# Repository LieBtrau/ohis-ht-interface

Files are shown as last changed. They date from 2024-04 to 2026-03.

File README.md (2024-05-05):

# OHIS-interface
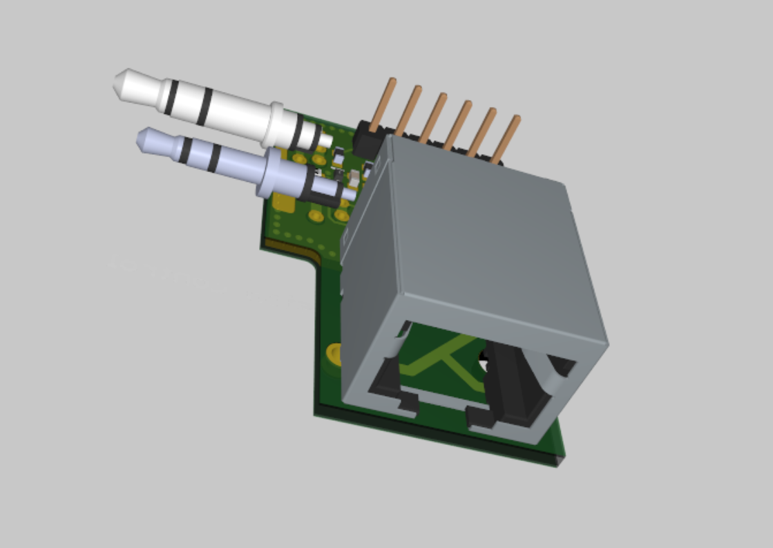
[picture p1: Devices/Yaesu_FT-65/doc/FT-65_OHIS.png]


According to [the OHIS-reference document](https://open-headset-interconnect-standard.github.io/ohis/Open-Headset-Interconnect-Standard.pdf):
> With the Open Headset Interconnect Standard, or OHIS, the club/EOC can build/buy one adapter for every
radio which stays with that radio, and the user only needs to build/buy one adapter for their specific headset
which stays with their headset, and now they can achieve full interoperability with only O(N) adapters.

# Criticism to OHIS
* Too many rigs are already using 8C/8p-modular jack connectors, but with a different pinout.  There's a big chance of breaking the radio if you plug in the wrong headset.
* The hook on the modular jack easily breaks if you don't protect it.
* One ground wire for mic and a separate ground wire for everything else would be enough instead of all the ground wires in the OHIS standard.
* When compared to a 3.5mm TRRS jack and cable, the modular jack is quite a bulky connector.

# Alternative interfaces
## CAIRO
* [CAIRO](https://web.archive.org/web/20060618023257/http://www-users.aston.ac.uk/~bestpj/cairo/manual/engineering.html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) : based on DIN-connectors, which are quite big as well.  They are however relatively common, cheap and easy to find.

## SATA-interface
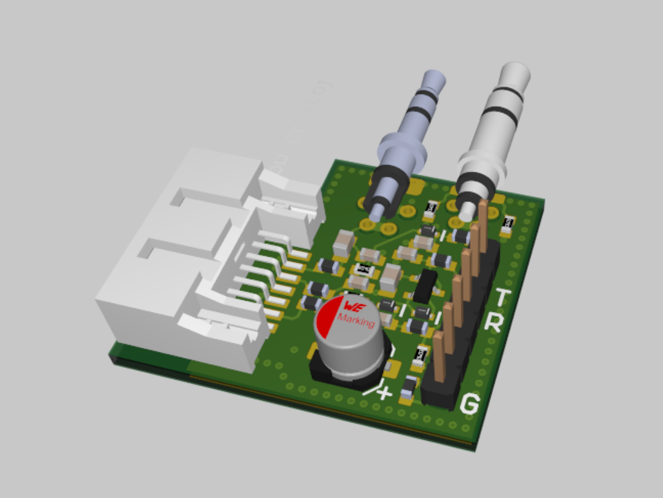
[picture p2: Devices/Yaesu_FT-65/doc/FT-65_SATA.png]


The SATA-interface is a low profile alternative to the modular jack.  It's easy to find cheap cables and connectors for it.  The SATA-connector has a locking mechanism, which is a big advantage over the TRS-jack.

Just to make it clear : this is not a SATA-interface, so you can't connect it to your hard drive.  We use the SATA-connector, but don't follow the SATA standard.  Confusion is very unlikely because the use case here is very different from the normal use case inside a computer.

The SATA connector has two differential pairs and three ground wires.  The differential pairs are used for the speaker, microphone, PTT and power.  The ground wires are used as current return path.  

| Pin | Signal | Description |
| --- | --- | --- |
| 1 | GND | Ground |
| 2 | SPK | Speaker |
| 3 | VCC | Power, max 5V, 200mA |
| 4 | GND | Ground |
| 5 | PTT | Push-To-Talk |
| 6 | MIC | Microphone |
| 7 | GND | Ground |

# Interface boards
This repostiory contains interface boards for the OHIS and SATA interfaces.  The interface boards are designed in Altium.

## Yaesu FT-65E
The OHIS- and SATA-interface to the FT-65E are also providing a pin header for UART interface to the radio.  This allows you to program the radio using a USB-UART converter and [CHIRP](https://chirpmyradio.com/projects/chirp/wiki/Home).  

* [Radio technical doc](./Devices/Yaesu_FT-65/Yaesu_FT65-E.ipynb)
* [OHIS FT-65E interface, version 1.0.0 (Altium online viewer)](https://365.altium.com/files/52D7B6AC-E25B-4030-AC4F-B64CA4D52889)
* [SATA FT-65E interface, version 1.0.0 (Altium online viewer)](https://365.altium.com/files/A41D46D5-1541-4C2A-84D1-905C59505208)

## Midland G9 Pro
* [Radio technical doc](./Devices/Midland_G9_Pro/MidlandG9pro.md)

These interfaces might work on more radios, but they have only been tested on the radios listed above.

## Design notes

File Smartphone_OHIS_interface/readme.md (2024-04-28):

# Measurements
## Maximum mic level
### Hardware setup
1. Connect TRS-cable to sound card (Tip=audio out, Sleeve=GND). 
2. Connect a TRRS-cable to the smartphone (Sleeve=MIC, R2=GND).
3. Connect audio out of TRS with a capacitor to MIC of TRRS.
4. Connect an oscilloscope parallel to the TRRS-cable connections.
5. Connect a 1K resistor from MIC to GND.  The internal microphone of a smartphone headset has the same value.

### Software setup
1. Smartphone runs [Phyphox](https://phyphox.org/) : Audio Scope
2. Laptop runs [REW](https://www.roomeqwizard.com/) : Generator
3. Generator set to 0dB.
4. Increase output volume setting of the laptop just before clipping occurs on the Audio Scope.

### Result
Maximum mic level is 30mVrms before clipping occurs.

## Maximum headphone level
### Hardware setup
1. Connect TRRS-cable to the smart phone
2. Connect oscilloscope between TIP and R2.

### Software setup
1. Smartphone runs [Phyphox](https://phyphox.org/) : Tone Generator
2. Set frequency to 1kHz
3. Set audio level of smartphone to maximum

### Result
AC-level = 457mVrms, DC-offset = 0V

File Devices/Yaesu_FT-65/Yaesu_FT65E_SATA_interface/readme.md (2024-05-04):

# Headphones
* 0dBV to -10dBV into a 16ohm to 64ohm load, a series resistor will be needed to drop the voltage to the correct level.
* No audio transformers because the radio only has 1 ground connection
* The radio has an H-bridge output stage.  The output is at 1.85V when no audio is present.  A capacitor is used to block the DC voltage.
* A small capacitor, parallel to the headphones, is used to filter out the high frequency noise.
* Only one channel is used to feed both headphones.  The radio has a mono output.  This reduces the number of components needed.

# Microphone
* The SATA interface is AC-coupled to the radio, but that should not be needed.  The 1uF can be replaced by a 0ohm resistor.

# Connection to the radio
* TRS-plugs (3.5mm and 2.5mm) and can be soldered directly to the interface:
  * Solder sleeve to the PCB.
  * Solder tip and ring using a loops of wire through two holes on either side of the plug.
* No filtering on TRS-plugs.
* GND of radio is directly connected to GND of interface.

# Connection to a sound card
Might also be connected to [Ai-thinker esp32-audio-kit](https://docs.ai-thinker.com/en/esp32-audio-kit), which uses an [ESP32-A1S module](https://docs.ai-thinker.com/_media/esp32-a1s_v2.3_specification.pdf)
Requires two 3.5mm TRS-jacks.  One for (line) input and one for (headphone) output.

# Isolation
If isolation is really needed, then an OHIS-OHIS interface could be created that contains two audio transformers.

# Connection to UART interface
* 6 pin JST XH connector (2.5mm pitch) to avoid wrong connection
* USB-UART bridge:
  * [Adafruit CP2102N Friend - USB to Serial Converter](https://www.adafruit.com/product/5335)
  * [Adafruit 70](https://www.adafruit.com/product/70)
  * [FTDI  TTL-232R-3V3](https://ftdichip.com/products/ttl-232r-3v3/)

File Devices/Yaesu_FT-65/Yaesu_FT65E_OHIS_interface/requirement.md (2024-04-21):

# Requirement
1. OHIS-compliant interface to handheld radio
2. Small form factor
3. Has 6 pin serial interface for programming
4. Solder pads for a custom cable
5. Plugs directly in the radio, avoiding custom cables or adapters
6. RF-filtering on all IO-connections
7. Clear labeling of all connectors

# Optional
1. audio jacks for connecting to a sound card or other audio device

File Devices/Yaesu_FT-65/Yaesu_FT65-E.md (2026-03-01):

## Yaesu FT-65E
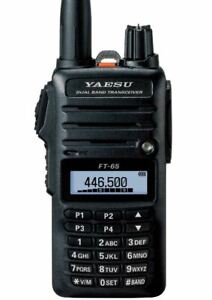
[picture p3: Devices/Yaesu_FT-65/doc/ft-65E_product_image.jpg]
Yaesu FT-65E product image
 

### Radio settings
#### Transmit power
* 0.5 W (Low)
* 2.5 W (Middle)
* 5.0 W (High)

#### Receiver sensitivity
* 0.2 μV (-121dBm) for 12 dB [SINAD](https://en.wikipedia.org/wiki/SINAD) (420 - 470 MHz, NFM)

#### PMR446
European version of the FT-65 can listen to PMR446, but is not allowed to transmit on that band.  Transmission on PMR446 is only allowed with PMR446-certified radios (fixed antenna, TX-power limited to 0.5W, ...), which the FT-65E is clearly not.

It's however technically possible to use a Yaesu FT-65E on PMR446:

1. Expand TX-range of a Yaesu FT-65E outside the ham-bands using this guide [here](https://simonthewizard.com/2017/12/17/yaesu-ft-65-expand/).
2. Set the following menu options in the FT-65E:
    * **32 : TX Power** : LOW (which is 0.5W)
    * **37 : WIDE/NAR** : NARROW (+/-2.5kHz deviation), when set to wide the Midland cuts off reception above 800Hz.
3. Set the TX-frequency equal to that of a PMR446-radio.
4. Frequency step : 
    * **30 : STEP** : 6.25kHz
5. Squelch type:
    * CTCSS:
      * **8 : CTCSS** : set up the same as a PMR446-radio.  On Kenwood PMR446 handsets, this will be called "Quiet Talk (QT)" setting, but it's essentially the same thing.
      * **29 : SQL Type** : TSQL
    * DCS:
      * **11 : DCS-code** : e.g. RX : 754, TX : 754
      * **29 : SQL Type** : DCS
6. Monitor / Tone calling.  The monitor button can be repurposed to send tone calling signals:
    * **9 : MONI/T.CALL** : 
      * MONITOR : monitor button is used to open squelch
      * other settings are for tone burst
     
### Antenna
During the tests:
* Set the TX power level (32:TX PWR) to LOW (0.5W)
* Replace the antenna by an RP-SMA to SMA adapter and add a 50Ω terminator.

### Audio IO
Don't turn the volume knob more than 50% to avoid distortion.  
Maximum undistorted audio output is 4.65Vpp, 1.85Voffset at 1kHz.

Maximum analog input voltage peak-peak for the Yaesu FT-65E = **30mVpp**

#### TX-Delay
This is the delay needed between pushing the PTT-button and the FT-65E being ready to transmit.  The delay is measured using a 1kHz sine wave signal.

* From Yaesu PTT-down to Midland G9 Pro opening its squelch = <144ms.
* From Yaesu PTT-down to Midland G9 Pro which has squelch-open all the time = <110ms.  Most of the times, it's between 80ms and 100ms.

#### TX-Tail
This is the delay needed between releasing the PTT-button and the FT-65E stopping to transmit.  The delay is measured using a 1kHz sine wave signal.

* From Yaesu PTT-up to Midland G9 Pro (squeltch-open all the time) = <170ms.  Most of the times, it's between 120ms and 140ms.

Motorola M1 connector : 7.62mm spacing between TRS-jacks.
* The threaded insert has an unknown screw thread.  It's close to M2.5, but not exactly the same.
* 3.5mm : 
  * Tip = speaker- (Vcm = 2.5V)
    * Jumps to 2V when squelch is open.  Audio max = 4V (with respect to GND)
  * Ring = ?
    * internal 10K PU to 3V3, unknown purpose
    * Short circuited to sleeve when using the SSM-17B Hand speaker Mic. Maybe that's the reason why Yaesu doesn't market the SSM-17B as an accessory to the FT-65.  The SSM-512B is advised instead.
  * Sleeve = speaker+ (Vcm = 2.5V)
* 2.5mm : 
  * Tip = Connect a PTT switch in series with electret-MIC (1K8 or 2K2 internal resistance) connected to GND.  Function generator outputs must be AC-coupled to this input, otherwise the PTT functionality no longer works correctly.
  * Ring = RX/TX line
    * RX/TX Short circuited to sleeve when using the SSM-17B Hand speaker Mic.
    * Use open drain TX and connect it to RX.  
    * To interface to a standard UART: connect the anode of a diode to the UART-RX. Connect the cathode of that same diode to the UART-TX. 
  * Sleeve = GND
    
### References
* [Packet radio projects (including APRS)](https://sites.google.com/site/rio4br/Home/aprs)
* [Ham.stackexchange.com](https://ham.stackexchange.com/questions/11776/what-is-the-external-mic-speaker-pinout-for-the-yaesu-ft-4xr-ft-65r-ft-25r)
* [Autocom intercom integration](http://largiader.com/electric/autocom.html)
* [BOMMEOW PARENT-BCT35-M1 3-Wire Acoustic Clear Tube Earpiece for Motorola Mototrbo CLS1410 XT460 DLR1020 Bearcom](https://www.bommeow.com/products/bommeow-parent-bct35-m1-3-wire-acoustic-clear-tube-earpiece-for-motorola-mototrbo-cls1410-xt460-dlr1020-bearcom)

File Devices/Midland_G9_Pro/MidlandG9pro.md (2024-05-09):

# Midland G9 Pro

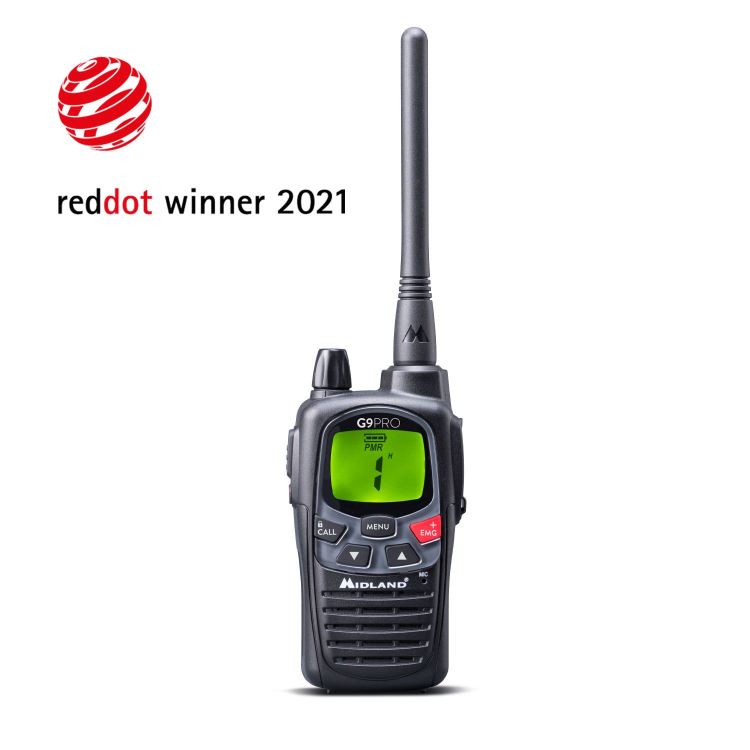
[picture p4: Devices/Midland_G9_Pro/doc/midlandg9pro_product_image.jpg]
Midland G9 Pro product image
 

* [User manual](0e696682f9c9f13678aeb36db453cce81be4fc38_MANUAL_G9_PRO_UK.pdf)
* Costs around €80 - €100.

## Disadvantages
* LCD-screen viewing angle is limited.
 
## Radio settings
### TX-output power
* L = 10mW
* H = 500mW

### Receiver sensitivity
* 0.35µV (-116dBm) (12dB [SINAD](https://en.wikipedia.org/wiki/SINAD))

### Channel settings
* [Channel list](./doc/8f8ebdc9da1fd9110cbd3557c7c3e5df0c08e5ac_CHANNELS_G9_PRO.pdf)

The radio can work with two different PMR-channel sets:
1. G9 PRO traditional band : 8 frequencies (from 446.00625MHz to 446.09375 MHz, 12.5kHz steps)
   * channels 1 to 8 : with configurable CTCSS/DCS
   * channels 9 to 16 : with CTCSS fixed to code 16 (114.8 Hz)
   * channels 17 to 24 : with CTCSS fixed to code 31 (192.8 Hz)
2. G9 PRO (new band) : 16 frequencies (from 446.00625MHz to 446.19375 MHz, 12.5kHz steps)
   * channels 1 to 16 : with configurable CTCSS/DCS
   * channels 17 to 32 : with CTCSS set to code 16 (114.8 Hz)

### Squelch
Opening the squelch/monitor : keep pressed for about 2 seconds both ▲▼ at the same time. Follow the same procedure to deactivate the function, or
switch off and on the radio.

#### DCS codes
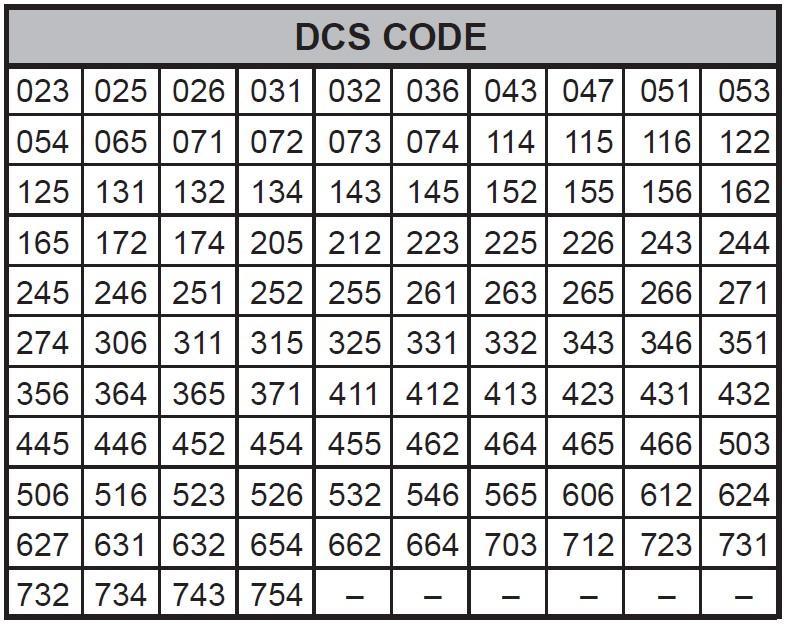
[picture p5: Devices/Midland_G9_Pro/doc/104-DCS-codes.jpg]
DCS-codes


#### CTCSS codes
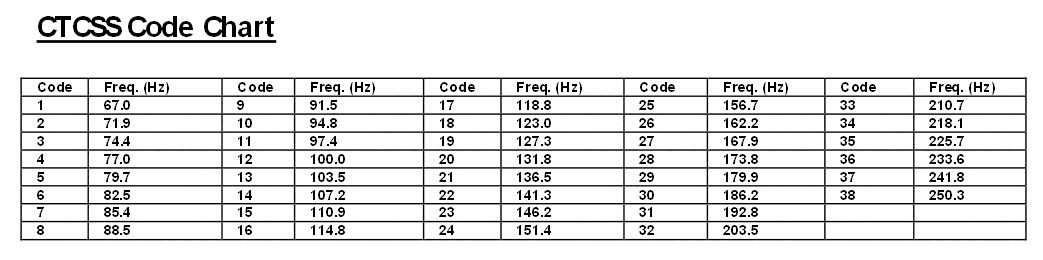
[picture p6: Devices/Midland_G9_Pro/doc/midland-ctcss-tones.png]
CTCSS-tones


## Audio IO
Midland 2prong pinout

* 3.5mm : 
  * Tip = Speaker + : 
  * Ring = ?
  * Sleeve = GND (Speaker -)
* 2.5mm : 
  * Tip = MIC_IN
    * Option 1 : Connect a PTT switch in series with electret-MIC (1K internal resistance)
    * Option 2 : Connect audio output of TNC between MIC_IN and GND.  Add a 2K2 resistor between MIC_IN and GND to activate PTT.
  * Ring = ?
  * Sleeve = GND (connected to 3.5mm sleeve inside the radio)

Don't fit a Kenwood K-1 connector in here.  It fits, but the pinout is different.
  
### Analog output
* Maximum audio output level is about 3Vpp.  Be careful : turning your volume knob open too far will cause your audio to clip, causing heavy distorted sound.
* Vcm when no audio is present = 2.40V
* Vcm when producing audio at max amplitude = 2.50V

### Analog input
PTT is activated by pulling MIC-IN to GND with a 2.2K resistor.

#### TX-Delay
Tested with 1kHz sine wave.
* From PTT down to squelch opening on FT-65 : <200ms, most of the times around 150ms.
* From PTT down to FT-65 receiving audio (with squelch continuously open) : <150ms, most of the times around 100ms.

#### TX-tail
Tested with 1kHz sine wave.
* From PTT up to squelch closing on FT-65 : <400ms
* From PTT up to FT-65 (with squelch continuously open) not receiving audio anymore : <350ms

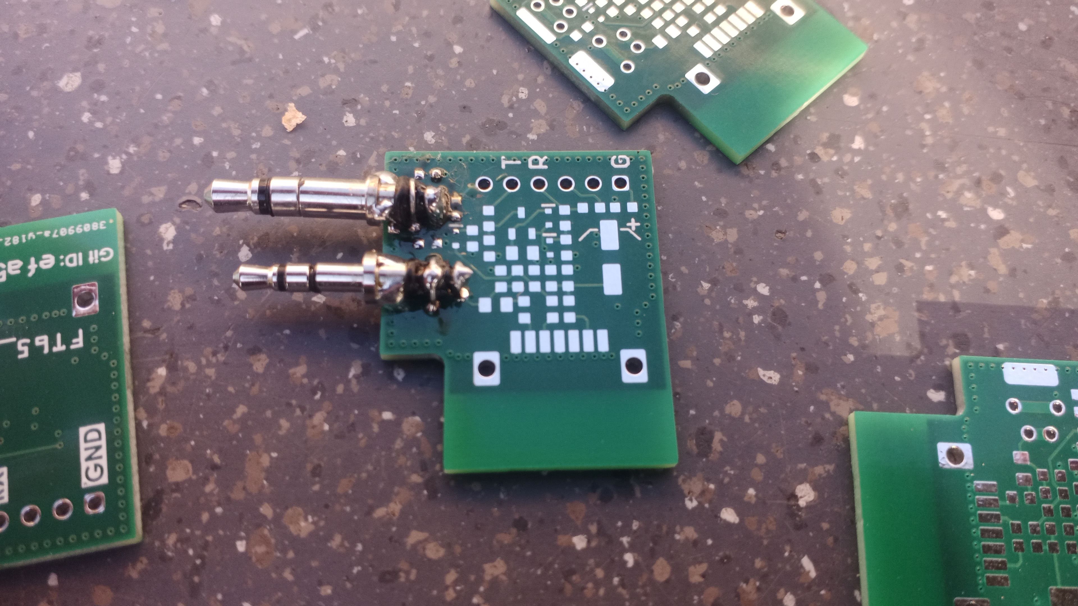
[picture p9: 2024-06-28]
pix/molten_connector.jpg

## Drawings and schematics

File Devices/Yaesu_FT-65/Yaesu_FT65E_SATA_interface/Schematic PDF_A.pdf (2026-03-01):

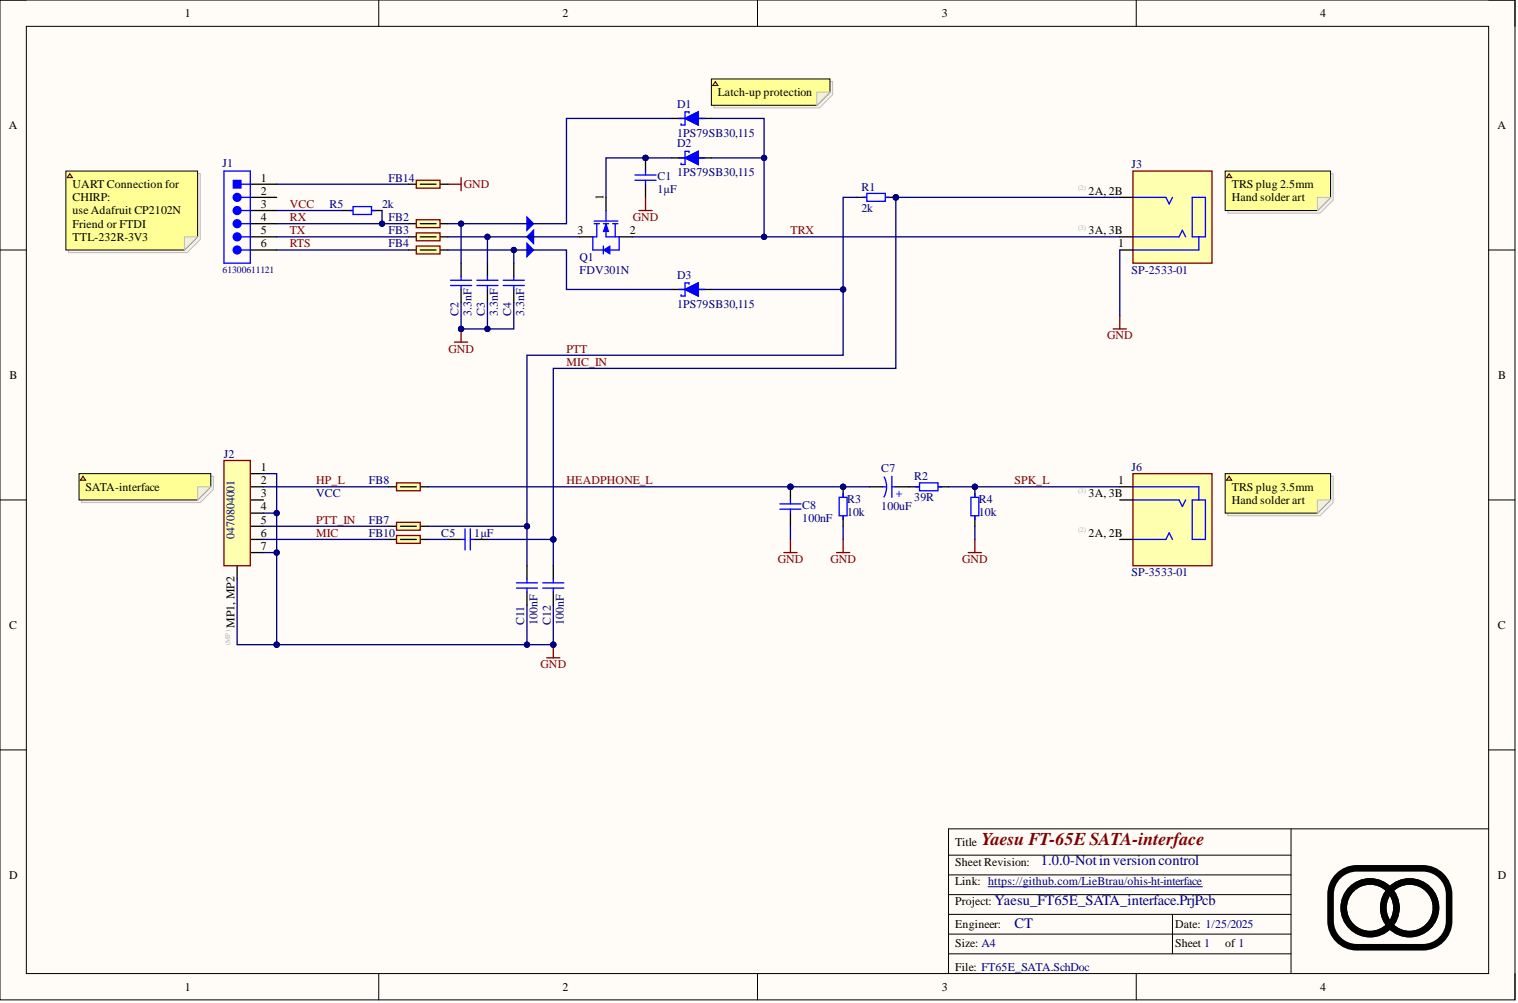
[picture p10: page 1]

GND | C1

Q1 FDV301N

PTT

3 | VCC

Yaesu FT-65E SATA-interface
Title
Sheet Revision:
Link: https://github.com/LieBtrau/ohis-ht-interface
Project:

1.0.0-Not in version control

Engineer: CT | Date: 1/25/2025
Size: A4 | Sheet 1 of 1

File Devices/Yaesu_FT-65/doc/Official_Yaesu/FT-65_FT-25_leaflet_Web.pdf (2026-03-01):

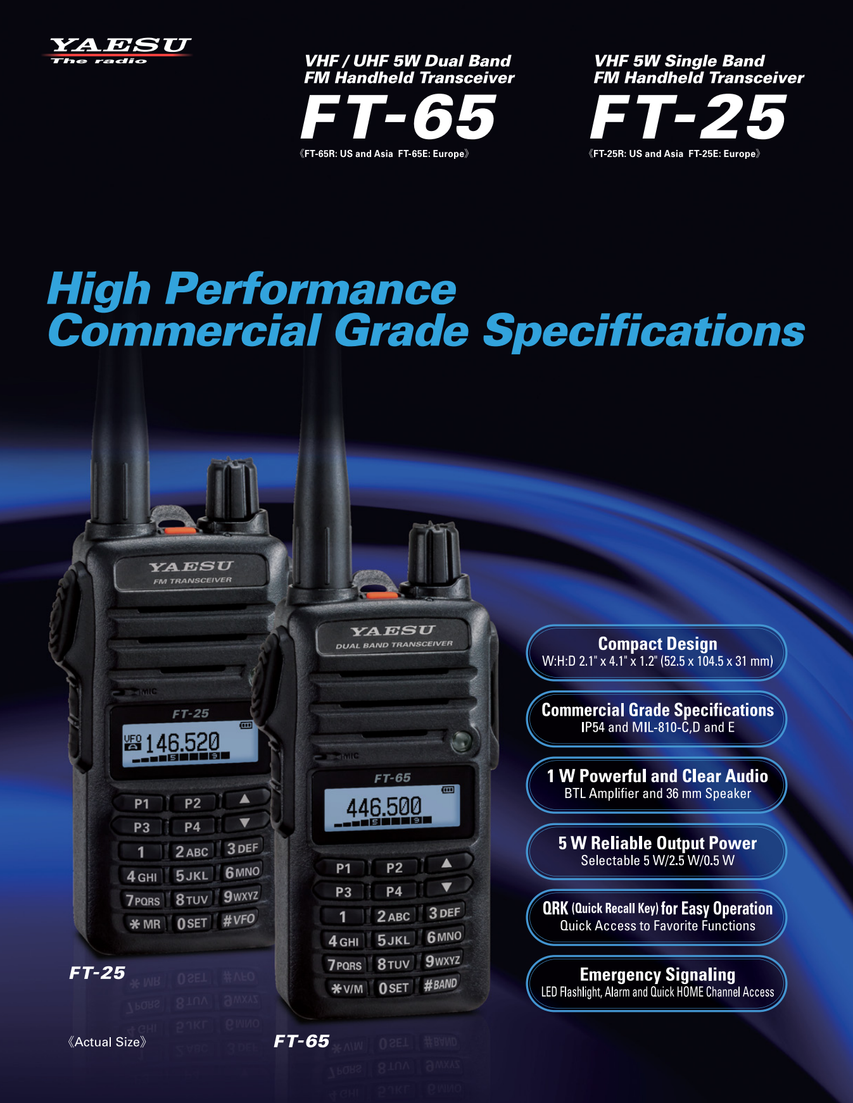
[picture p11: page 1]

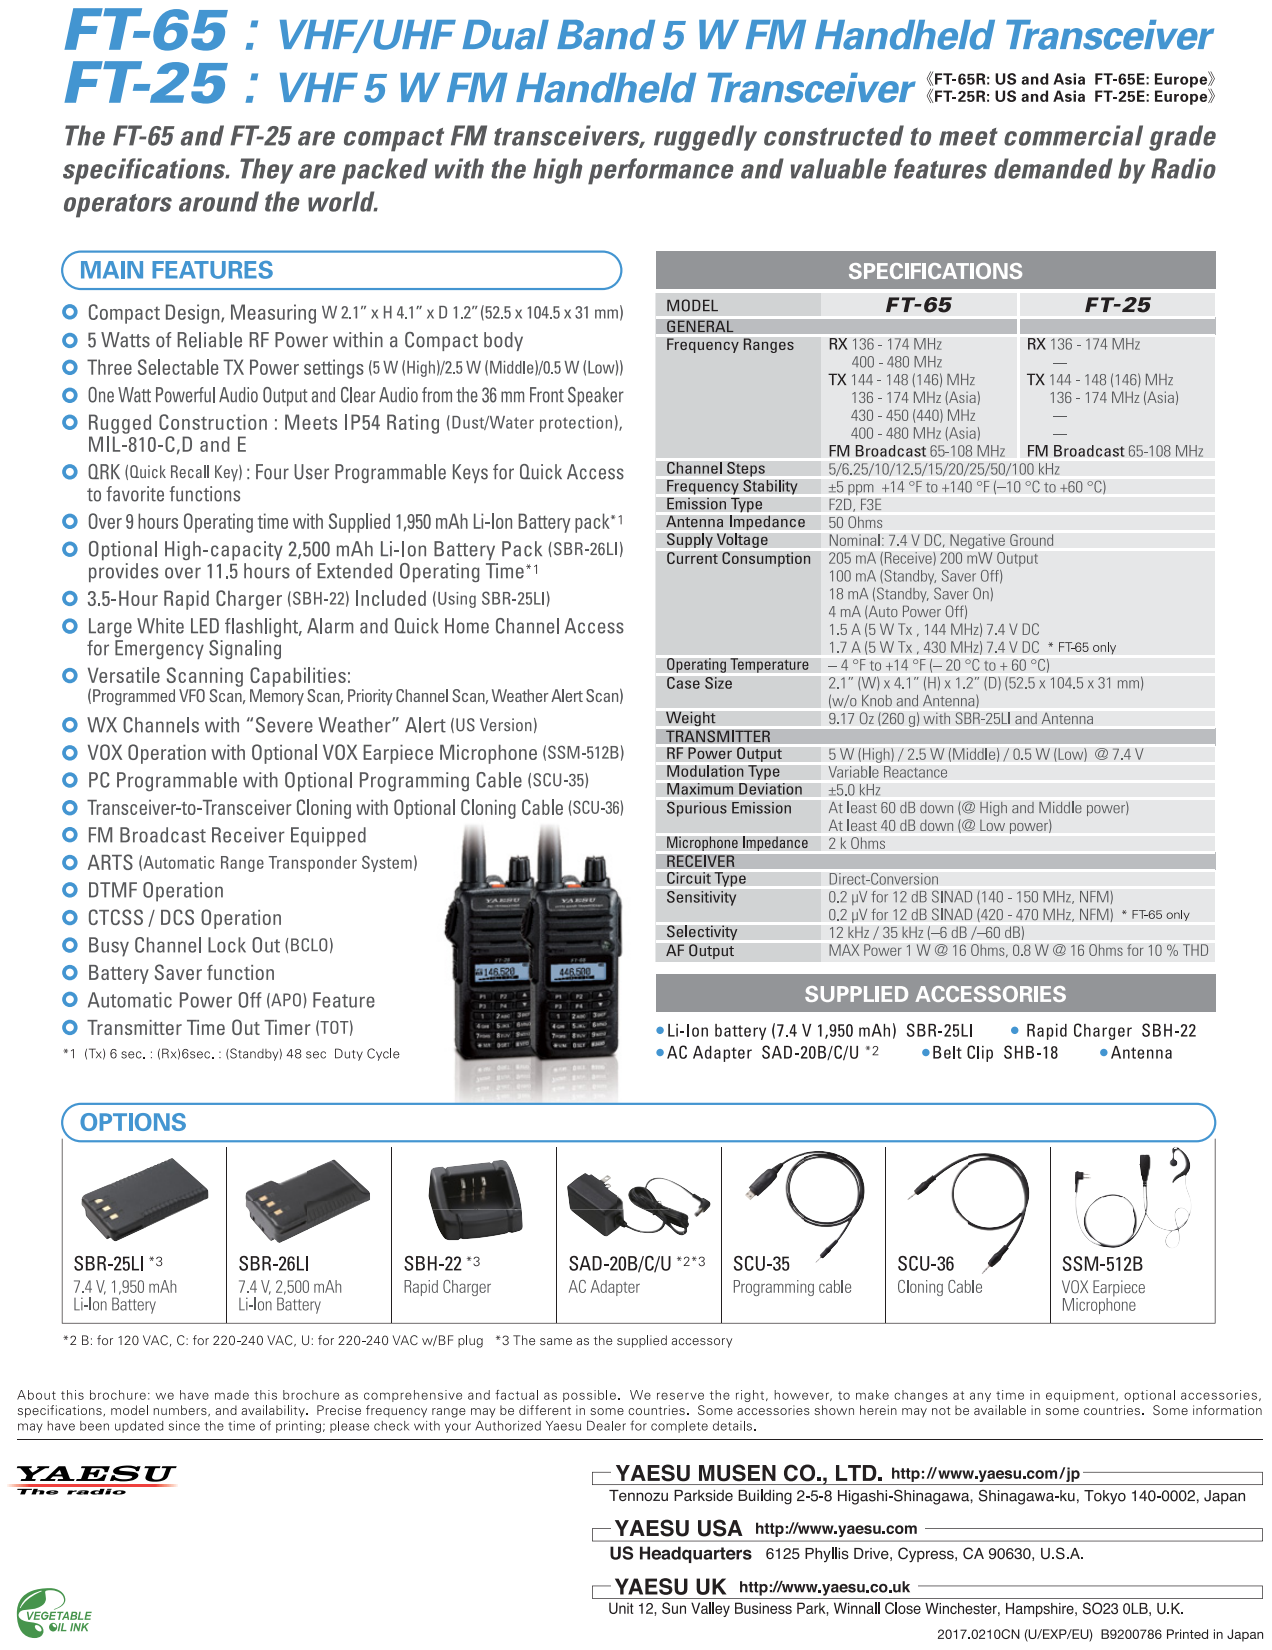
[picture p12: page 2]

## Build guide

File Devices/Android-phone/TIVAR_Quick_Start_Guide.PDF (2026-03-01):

### Using Tivar for Receiving Short Wave Radiograms

For Version 1.2.0 and later. | As of 20th of August 2019.
(1) Overview

Tivar stands for “Text-and-Images-Via-Analogue-Radio” has described by Kim Elliott (KD9XB).

I was designed to receive SW Radiograms, including MFSK pictures. It has no transmitting capability.

Since it also supports UTF-8 characters decoding, it will print all Left-to-Right alphabets and most (maybe all) Asian characters which use that encoding scheme.

It is designed to runs on Android devices (phones and tablets) from version 4.0.1 (Android Ice Cream Sandwich) and later.

Most phones and tablets of these Android versions should be able to decode any of the listed modes without limitations.

It is not available on the Google Play Store but can easily be download and installed on the Android devices.

It is capable of decoding the following digital modes:

- RSID (Reed-Solomon Identification) to detect the digital modes about to be transmitted and align the audio frequency of the modem.
- MFSK 16, 32, 64, 128, 64L and 128L.
- PSK 31 to 1000, PSKR (robust PSK) 125 to 1000 and all multi-carrier PSK and PSKR modes found in Fldigi. 8PSK125, 250 and 500, but not the faster 8PSK1000 and 1200 modes from Fldigi as they are not reliably decoded on phone devices.
- All the Olivia modes associated with an RSID (from Olivia 4-125 to Olivia 64-2000)
- THOR 11, 16, 22, 25x4, 50x1 50x2, 100.
- MT63 in all six combinations found in Fldigi (Short and Long interleave in 500, 1000 and 2000 Hz bandwidth versions) .
- DominoEx 22, 44 and 88 but without FEC (as THOR is a very similar modulation with FEC).

It saves the broadcast sessions in text and image files stored on the devices.
Storage requirements are pretty minimal as the disk sizes for both saved text and images are counted in tens of KBs (Kilo Bytes).

Simply placing the device near a radio receiver’s speaker in a low noise environment produces acceptable results for test or demonstration purposes.
Using a proper cable connection to the devices audio jacks produces better results especially for images.

(2) Quick start

To install, using the device's browser, download the .apk file at https://sourceforge.net/projects/fldigi/files/AndFlmsg/TIVAR/.

Note that “Allow unknown sources” needs to be selected first in the security or application section of the device settings.

Use a file manager to select and launch the .apk file’s installation. More detailed installation instructions are available below in section (3).

When first launched, you will be prompted for a series of permissions if your device if using Android 6 or later. Just accept these permissions. The program is not allowed to run without these.

On subsequent launches, the application will directly displays the terminal screen.

Navigate to the Modem screen by a left swipe movement on the screen (see below).

Ensure that the squelch level, represented by the more transparent indicator in the “S2N” bar just above the buttons, is set to a low level, typically 1/5 of the screen on the left of the bar, or less. Higher values may prevent reception of text during fades and interferences.

If you want to see the waterfall, press the “W.Fall On/Off” button.

The menu button (earlier phones) or menu icon on the screen (tablets/latest phones) brings a menu to exit the application and change the Settings.

Important Note: as long as Tivar is running (i.e has not been “exited”), it will use the microphone as its input and therefore will prevent other apps like Skype for example from using it.

Always press Menu then Exit when you are finished with Tivar.

A yellow antenna icon is displayed as a reminder at the top or bottom of the screen while the modem is running.

All the received broadcast text files and images are stored on the device default memory under the directory TIVAR.files.

RSID is a series of short tones before a transmission which identifies the digital mode being used. It allows the receiving app to switch immediately to the proper mode and audio frequency for the best reception of the incoming transmission, being text ot image. In Tivar the reception of RSIDs is always On.

(3) Operation
1. The simplest way to get the audio in the Android device is by using the built-in microphone. This is called audiocoupling. It provides quite acceptable results provided a few precautions are taken:
- The microphone hole on the device is placed as close as practical to the radio's speaker. A distance of a few centimeters works well.
- The place is not noisy.
- The device is not moved or bumped against the radio during listening.
2. As text is received, it is displayed in the Modem screen and is automatically saved into a “broadcast file”. The name of the file contains the start date and time of the when receiving was commenced.
3. To separate the received text into a new broadcast file, press the “New Log” button. A new file will be created in the TIVAR.files/Broadcasts directory on the device.
4. The broadcast file names have the following format: YYYY-MM-DD_HHMMSSz.txt, where YYYY-MM-DD is todays’ date and HHMMSS

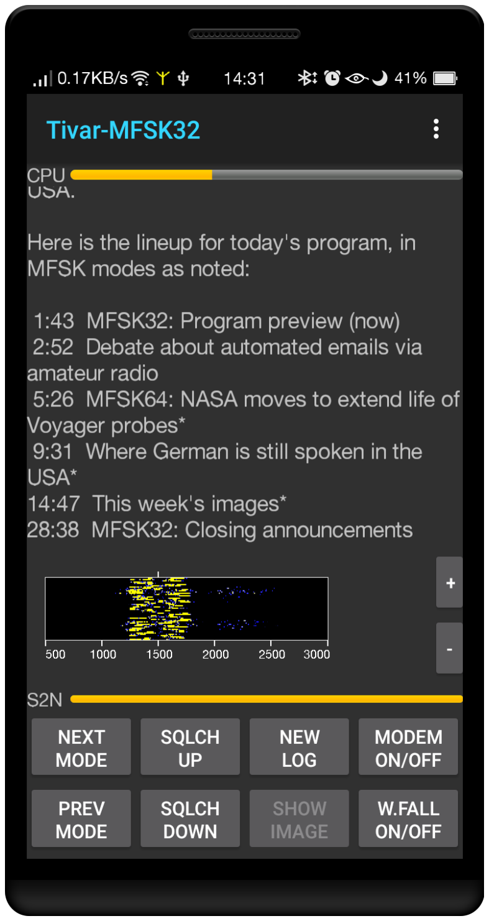
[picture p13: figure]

is the time when the file was created. The “z” at the end is to remind us that this time is the UTC or “Zulu” time, not the local time.

5. When an MFSK image is
received, a window will pop-up in front of the Modem screen. The image will be updated as reception progresses. The
received image will be saved automatically in the “Images” directory of the TIVAR.Files directory.

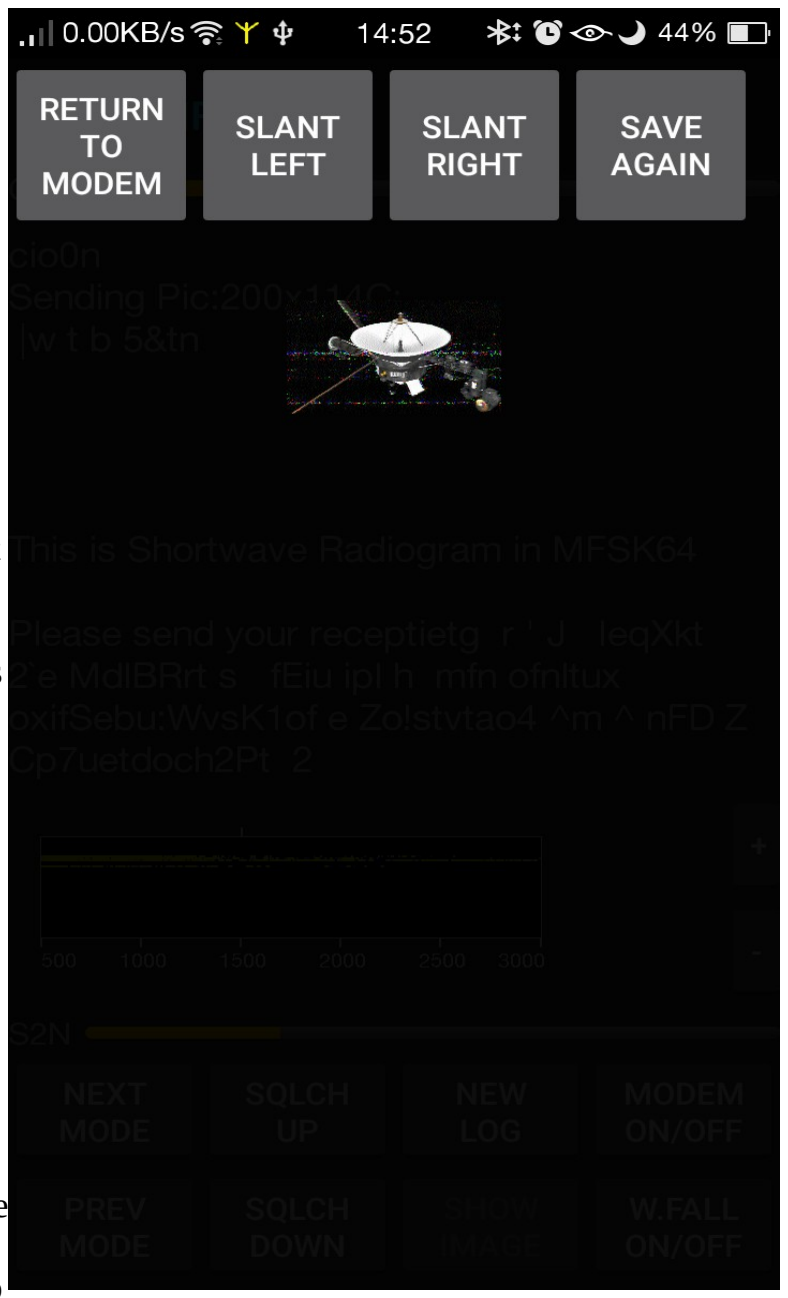
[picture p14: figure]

6. When the reception of the image is complete, the three right most buttons become available and allows the correction of the slant (the bottom left or right edges of the images are like “wrapped around”). When the correction is done, press “Save Again” to save the corrected picture.
7. Closing the image popup view does NOT stop the image
reception and therefore the “Return button” can be pressed at any time, BUT if pressed before the image is fully
received there is no way to correct the slant afterwards.
8. The reception of text will resume
as soon as the image reception is
completed, so there is no need to
close the image window “in a hurry” after the end of an image reception.
9. The images are automatically inserted in the Android Gallery. Open the Gallery app, and select either the “Tivar-Images” album or the “All Albums” view. The received images are in order of reception. The file names carry the time stamp formatted like the broadcast file format (see above).
10. The CPU load, displayed as a horizontal bar at the top of the Modem screen, should not be higher than 75% (¾ to the right) on average. If it is higher than that, go to the menu, select preferences, then navigate to Modem/Slow CPU and tick the check box. Note that displaying the waterfall also increases the CPU load.

(3) More detailed Installation Instructions

Download the Tivar apk file from the website at:

https://sourceforge.net/projects/fldigi/files/AndFlmsg/TIVAR/

And save it to the SD card, either from within the phone or on a PC to which the Android device is connected to and has the USB driver installed for that device to allow access to the SD card content from the PC.

From there use a file explorer app on the phone to install the .apk file.

You have to allow non-Android market application to be installed for this to work. This is found under Settings / Security / Unknown Sources OR Setting / Applications / Unknown Sources, for older versions of Android.

You will be asked to accept a series of permissions that are explained below:

a. Storage: Read and write to the SD card. For storing and accessing the working files under the "TIVAR.files" directory.
b. Network Communication as in Bluetooth and Full Internet access: to allow connection to the Bluetooth handsfree kits or headsets used as audio interfaces AND to share / Forward messages over the internet.
c. Hardware controls (audio settings and recording): required for receiving sound through the internal or external microphone.
d. Bluetooth administration: to redirect the sound via Bluetooth.

In your applications list you should now have a Tivar app icon which looks like:

(4) Interfaces between the Radio and the Android Device

Simple audio coupling (speaker to microphone) is giving good results, but for best performance an interface cable is required.

A simple DIY cable is described in the last page of this document.

Important: Simply plugging a stereo or mono jack to jack cable between the radio speaker/headphone output and the plug on the Android device is almost guaranteed NOT do what it is expected to do.

On some devices (e.g HTC phones) there is a visual icon which tells you if the
external mic is being used. If, at the top of your screen, you simply have the
headset icon, the internal mic is in use (see picture on the right).

If the icon shows both the headset and the mic icon, the external mic is in use (see picture on the right).

But a number of devices (e.g. Motorola Xoom and Samsung Galaxy Tab 2 to name the two I tested) do not show any icon. You have to rely on audio tests to determine which mic is in used.

Here is our experience with some commercial cables (Thank you for the tests Kim):

1. This one only works with a mono plug:
http://www.startech.com/Cables/Audio-Video/Audio-Cables/35mm-4-Position-to-2x-3-Position-35mm-Headset-Adapter-Male-to-Female~MUYHSMFF (http://www.startech.com/Cables/Audio-Video/Audio-Cables/35mm-4-Position-to-2x-3-Position-35mm-Headset-Adapter-Male-to-Female~MUYHSMFF)
2. This one works with a stereo plug:
https://www.sescom.com/products/view/product/productslug/trrs-right-angle-25db-35mm-line-leveland-35mm-monitor-jack
3. This adapter on the right (eBay for example) seems to work with
older devices but not newer ones. The issue is that the mic input is
connected directly to the TRRS plug. Maybe by inserting a 1.2KOhms in series with the mic tip it may work.

Technical explanation about the 4 way jack on Android devices:

Most Android devices can either use the built-in microphone or an external one through the 3.5mm plug. That plug has four connections internally and carry the two stereo outputs, the ground plus the mono microphone input. It is called a TRRS plug (for Tip, Ring, Ring, Sleeve).

A circuit at the end of this manual explains the circuit requirements in more details, but in a nutshell, the device will switch from it's internal mic to the external one ONLY if there is a defined DC load on the external mic connection.

That same mic input is also used for controlling some of the devices functions like accepting or hanging-up an incoming call, stopping or starting a music player and skipping to the previous or next song.

The action is determined by the DC load (typically a resistance) that the device sees on that mic pin. Different values equal different actions (E.g. Zero Ohms = Play/Stop/Answer/Hangup, 220 Ohms = Back, 600 Ohms = Forward, from around 1K to 1.5K is mic input alone).

This is why a simple jack to jack cable will most likely not make the device switch between internal and external mic.

The usage of an interface cable rather than simple audio coupling produces the best results:

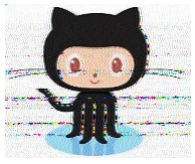
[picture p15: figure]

1. Image received without a cable (Speaker to Mic):

Note the wave effect on the right hand side of the picture due
to the presence of audio echos (table, walls etc..).

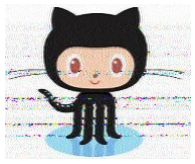
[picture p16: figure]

2. Image received with an interface cable (schematic below):

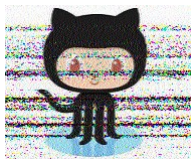
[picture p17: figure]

3. Image received with an interface BUT with the Slow CPU option turned ON. It shows more noise as filtering is disabled to save CPU load:

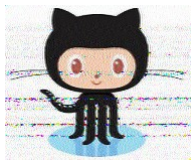
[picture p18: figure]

4. Reference image received by Fldigi using Audio Playback, very similar to image (2) with the interface cable:

(5) The Modem Screen in more details

Used to display the data received by the software modem and see an indicator of CPU load.

The top bar represents the CPU load with zero load on the left and 100% on the right. This is an indication of how much reserve the CPU has, rather than a true load indicator.

The bottom bar (2 overlaying bars in fact) represents both the squelch level and the current received signal quality. The brighter one is the signal quality and the darker one the squelch. Characters will be displayed when the brighter bar is longer than the darker (squelch) value.

The squelch up and down increases/decreases the

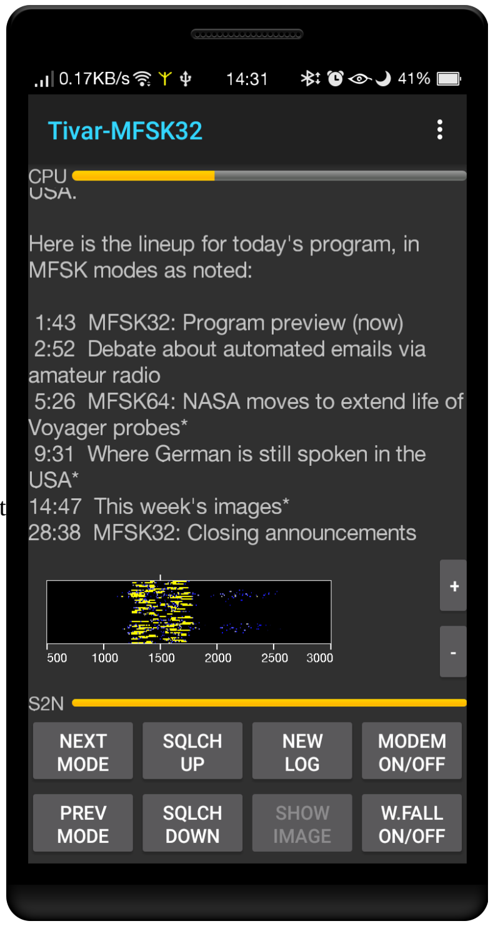
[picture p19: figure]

squelch value and stores it for later use so that it is set to the same value the next time the application starts.

The Next Mode and Prev Mode buttons will cycle either through your custom list of modes as set in the preferences OR through the whole list of modes available if the “Use custom list of modes” preferences is not set.

Modem ON/OFF stops/restarts reception and processing of incoming audio. This is to conserve processing and therefore batteries as well as freeing
the microphone input for other applications.

Note: Digital Modem reception is CPU intensive and the battery drain increases compared to a device in standby, particularly on phones. Use the Modem On/Off button to conserve battery.

The decoded RSID mode and center frequency are also displayed in the Modem screen.

The received modem data can be selected for copy and paste in another application like a text editor. Just “Long Press” on the text to bring the select/copy dialog on the screen. This is only available on devices with Android version 3.0 and above.
Note: The text can only be selected when the Modem is Off (Modem On/Off Button) as it makes the selection much easier and prevents the flickering of the screen when data is received.

The waterfall can be displayed by pressing the W.FALL on/off button.

The “New log” button starts a new receiving log file at the current time.

The “Show Image” button is disabled (for now).

The “+” and “-” buttons to the right of the waterfall adjust the sensitivity of the waterfall display.

Simple audio interface cable for Short Wave Radio

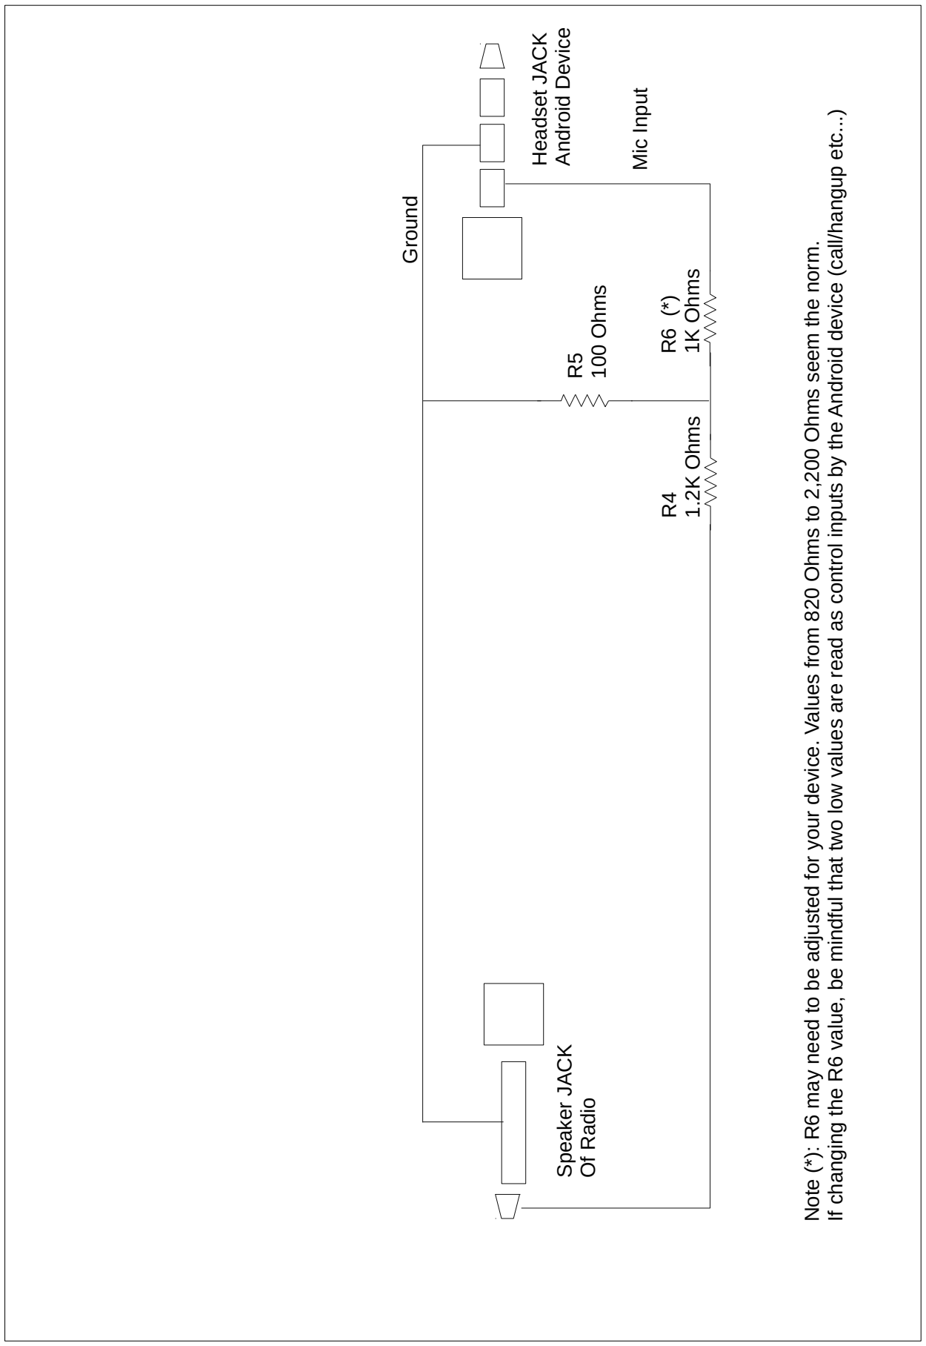
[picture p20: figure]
100 Ohms; 1K Ohms; 1.2K Ohms; Mic Input; Headset JACK; Android Device; Ground; Speaker JACK; Of Radio

Note (*): R6 may need to be adjusted for your device. Values from 820 Ohms to 2,200 Ohms seem the norm.

If changing the R6 value, be mindful that two low values are read as control inputs by the Android device (call/hangup etc...)

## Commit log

2024-04-13 First placement done.
    [OHIS_FT65E.PcbDoc, OHIS_FT65E.SchDoc, Yaesu_FT65E_OHIS_interface.PrjPcb]
2024-04-14 No filtering on TRS-connection
2024-04-16 PCB Layout finished
    [OHIS_FT65E.PcbDoc, OHIS_FT65E.SchDoc, Yaesu_FT65E_OHIS_interface.PrjPcb]
2024-04-21 Finalizing PCB layout and documentation settings
    [OHIS_FT65E.PcbDoc, OHIS_FT65E.SchDoc, Yaesu_FT65E_OHIS_interface.PrjPcb]
2024-05-04 Changing folder structure
    [OHIS_FT65E.PcbDoc, OHIS_FT65E.SchDoc, Yaesu_FT65E_OHIS_interface.PrjPcb]
2024-05-04 Add Yaesu FT65E SATA interface files
    [FT65E_SATA.PcbDoc, FT65E_SATA.SchDoc, Yaesu_FT65E_SATA_interface.PrjPcb]
2024-05-04 FT65E_SATA 1.0
    [FT65E_SATA.PcbDoc, FT65E_SATA.SchDoc, Yaesu_FT65E_SATA_interface.PrjPcb]
2024-05-04 Fix DRC
    [FT65E_SATA.PcbDoc]
2024-05-04 Ready for ordering
    [Yaesu_FT65E_SATA_interface.PrjPcb]
2024-05-04 Documenting MIC AC-coupling
2024-05-05 Migrating Yaesu FT-65 data from digital-walkie-talkie repository
    [FT65E_SATA.PcbDoc, FT65E_SATA.SchDoc, OHIS_FT65E.PcbDoc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]
2024-07-06 Add title for audio connectors
